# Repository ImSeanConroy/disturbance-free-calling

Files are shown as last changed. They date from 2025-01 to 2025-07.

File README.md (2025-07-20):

# Disturbance Free Calling

**Minimising disturbances to enable productive remote work** - In today's remote work environment, unintentional interruptions can disrupt productivity and communication. This project aims to solve that challenge by creating an IoT-powered availability indicator that minimizes disturbances during critical work activities such as calls and meetings.

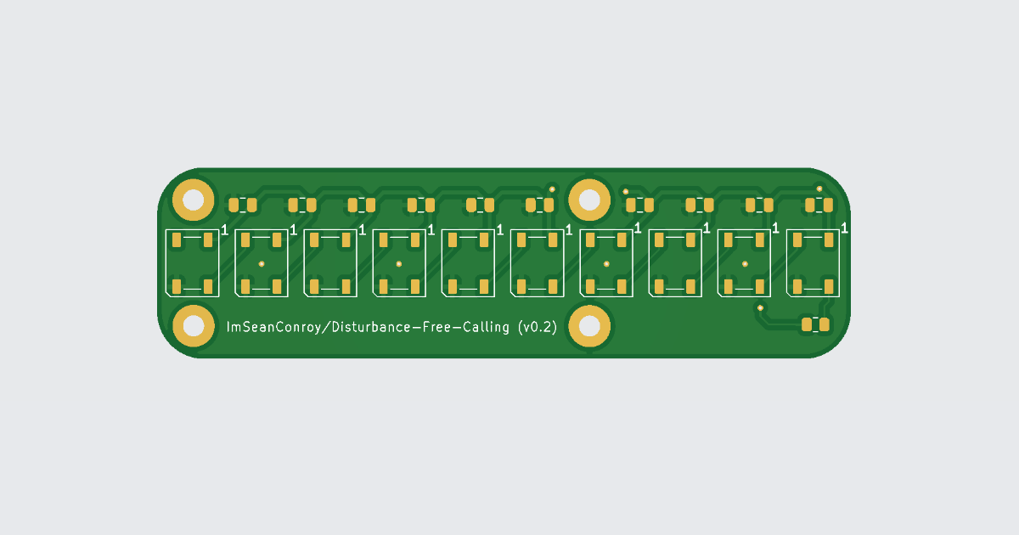
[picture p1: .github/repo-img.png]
Project Image


This is **version 2.0**, building on the foundations of the [original version](https://www.linkedin.com/feed/update/urn:li:activity:6930081862153342977) developed in 2020. The initial solution utilized an **ESP32 microcontroller based development board** to poll the **Webex API** and display availability using an **LED strip**.While effective, it had room for improvement in **performance, reliability, and design** — which are now addressed in this upgraded version.

## Table of Contents

- [Monorepo Structure](#monorepo-structure)
- [Features and Development Roadmap](#features-and-development-roadmap)
    - [Current Features](#current-features)
    - [Upcoming Features](#upcoming-features)
- [Architecture Diagram](#architecture-diagram)
- [Getting Started](#getting-started)
    - [1. Clone the Repository](#1-clone-the-repository)
    - [2. Hardware Setup](#2-hardware-setup)
    - [3. AWS Infrastructure Setup](#3-aws-infrastructure-setup)
    - [4. Firmware \& Device Setup](#4-firmware--device-setup)
    - [5. Configure Webex Webhook](#5-configure-webex-webhook)
- [Hardware Requirements](#hardware-requirements)
- [Contributing](#contributing)
- [License](#license)
- [Support](#support)
- [Acknowledgments](#acknowledgments)

## Monorepo Structure

This project uses a monorepo that includes:

- **Hardware** – KiCad PCB files for custom boards
- **Firmware** – ESP32 firmware to drive the LED indicator
- **AWS Infrastructure** – Terraform setup for API Gateway, Lambda, and IoT Core
- **Backend** – Node.js Lambda functions to handle Webex webhook data

## Features and Development Roadmap

This project is a work in progress, the following outlines the current features and planned improvements:

### Current Features

- **Terraform Provisioning** - Automates the setup and deployment of necessary cloud infrastructure.
- **Webhook Integration** - Allows seamless communication between the IoT device and external services.

### Upcoming Features

- **Custom PCB** - Designed specifically to support the IoT-driven indicator system.
- **Custom ESP32 Integration** - Incorporate the newly developed custom ESP32 board into the system architecture.
- **Web UI dashboard** - A web interface that allows users to override availability status manually.

## Architecture Diagram

Below is a high-level overview of how the architecture operates:

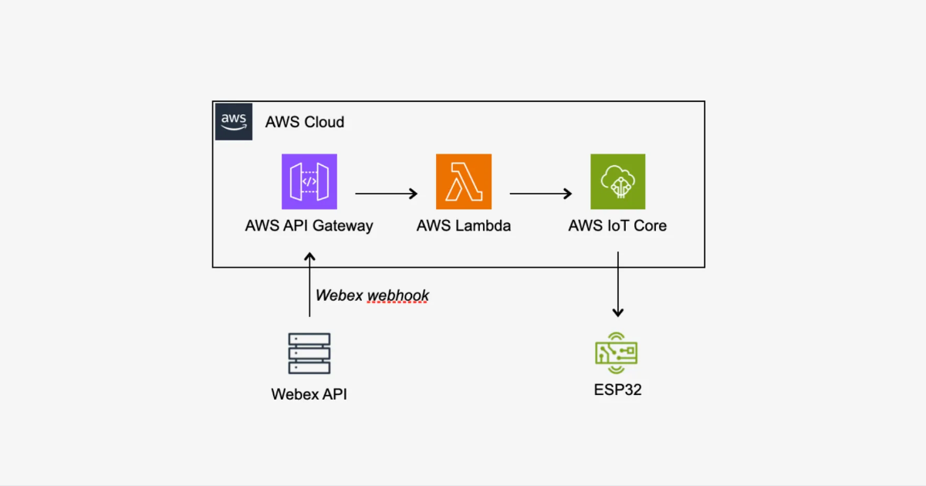
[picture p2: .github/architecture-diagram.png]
Architecure Diagram


**1. Webex Webhook → API Gateway** - A Webex webhook sends a request to an AWS API Gateway endpoint when a user’s availability status changes.

**2. Lambda Function → AWS IoT** - AWS API Gateway triggers an AWS Lambda function, which processes the Webex data and publishes the updated availability status to an AWS IoT Core MQTT topic.

**3. Device Subscribes → Updates LED** - The device subscribes to the AWS IoT topic and receives status updates, updatings the LED indicator accordingly.
 
> **Note**: A polling-based firmware version is available for setups that cannot use Webex webhooks. This version periodically queries the Webex API for status updates.

## Getting Started

Before getting started, ensure you have the following installed:

| Tool | Purpose | Link |
| --- | --- | --- |
| Node.js | Backend scripts & Lambda bundling | [Download](https://nodejs.org/) |
| npm | Node.js package manager | [Download](https://www.npmjs.com/) |
| Terraform | Infrastructure provisioning | [Install Guide](https://developer.hashicorp.com/terraform/install) |
| AWS CLI | AWS access & configuration | [AWS CLI](https://aws.amazon.com/cli/) |
| Arduino IDE | Firmware upload to ESP32 | [Arduino IDE](https://www.arduino.cc/en/software) |
| KiCad | Open/edit PCB files | [KiCad](https://www.kicad.org/) |

### 1. Clone the Repository

First, clone the repository to access the firmware, backend, and PCB files:

```bash
git clone https://github.com/ImSeanConroy/disturbance-free-calling.git
cd disturbance-free-calling
```

### 2. Hardware Setup

1. **Open the Project** - Open the `PCB/disturbance-free-calling.kicad_pro` file in KiCad to view the project.
2. **Review the Design** - Inspect the schematic and PCB layout to ensure it meets your needs.
3. **Customize or Export** - Make any modifications and export the Gerber files for fabrication.
4. **Order the PCB** - Submit the Gerber files to your preferred PCB manufacturer (e.g. [JLCPCB](https://jlcpcb.com/capabilities/pcb-capabilities)).
5. **Get the Components** - Purchase the components from the BOM and a compatible board.
6. **Assemble the Hardware** - Solder the components and assemble the board.

### 3. AWS Infrastructure Setup

1. **Zip AWS Lambda Function.**
```bash
cd Backend && npm run install && npm run zip && cd ..
```

2. **Configure Terraform Environment Variables.**
```bash
export AWS_ACCESS_KEY_ID=<your-access-key>
export AWS_SECRET_ACCESS_KEY=<your-secret-key>
export AWS_REGION=<your-region>
```

3. **Deploy AWS Infrastructure**
```bash
terraform init
terraform apply
```

4. **Extract AWS IoT Credentials** - Save these values and add them to your firmware:
```bash
terraform output root_ca_url
terraform output device_certificate
terraform output device_private_key
```

### 4. Firmware & Device Setup

1. **Open Firmware Sketch** - Load Firmware/AwsIotController/AwsIotController.ino in the Arduino IDE.
2. **Configure Device Credentials** - Add Wi-Fi SSID/password and paste the AWS IoT credentials into the appropriate constants.
3. **Upload to Device Firmware** - Compile and upload the sketch to the ESP32 using Arduino IDE. Test connectivity.

### 5. Configure Webex Webhook

> TODO: Add step-by-step instructions for setting up the Webex webhook and linking it to the API Gateway endpoint.

## Hardware Requirements

The following are the required components to build the 2x6 LED Matrix:

| Quantity | Component | Description | Source |
| - | - | - | - |
| 10 | WS2812B-V5 | Individually addressable RGB SMD LEDs | [TME](https://www.tme.eu/gb/details/ws2812b-v5/smd-colour-leds/worldsemi/) |
| 1 | Seeed XIAO ESP32C3 | Microcontroller board | [PiHut](https://thepihut.com/products/seeed-xiao-esp32c3?variant=53975115661697) |
| 1 | USB-A to USB-C Cable | For power and programming | [PiHut](https://thepihut.com/products/usb-a-to-usb-c-cable-1m?variant=42520360779971) |

## Contributing

Contributions are welcome. Please open an issue or submit a pull request for any enhancements or bug fixes.

## License

This project is Distributed under the MIT License - see the [LICENSE](LICENSE) file for information.

## Support

If you are having problems, please let me know by [raising a new issue](https://github.com/ImSeanConroy/disturbance-free-calling/issues/new/choose).

## Acknowledgments

This project was made possible thanks to the following resources:

- [AWS re:Post](https://repost.aws/questions/QUxlg-arOrTcaxFAdNEj7hqA/lambda-publish-a-mqtt-message-to-iot-core-inside-a-lambda-function-with-node-and-sdk-3) - Publish a MQTT Message to IOT Core inside a Lambda function with Node and SDK 3
- [AWS Samples](https://github.com/aws-samples/aws-iot-esp32-arduino-examples) - Several Arduino examples for AWS IoT projects using ESP32.

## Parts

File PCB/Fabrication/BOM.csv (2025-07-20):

Designator | Quantity | JLPCB Part # | Footprint
C2,C7,C3,C9,C8,C1,C5,C6,C4,C10 | 10 | C_0805_2012Metric | 100nF
D4,D1,D2,D3,D7,D8,D5,D9,D6,D10 | 10 | LED_WS2812B_PLCC4_5.0x5.0mm_P3.2mm | WS2812B
R1 | 1 | R_0805_2012Metric | 100uF
U1 | 1 | MOUDLE14P-SMD-2.54-21X17.8MM | MOUDLE-SEEEDUINO-XIAO-ESP32C3

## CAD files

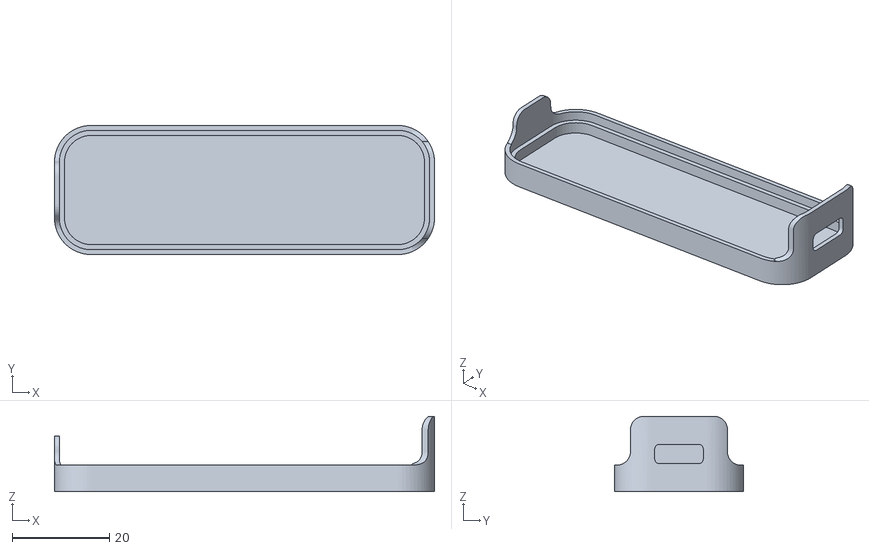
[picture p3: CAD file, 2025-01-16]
Case/back.stl
78.0 x 26.5 x 15.4

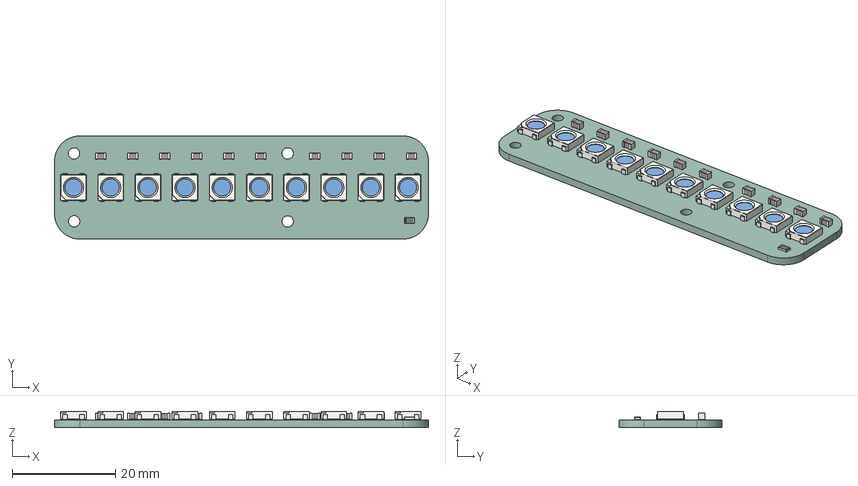
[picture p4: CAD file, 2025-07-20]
PCB/Fabrication/CAD.step
72.5 x 20.0 x 3.20 mm
C_0805_2012Metric x 10
LED_WS2812B_PLCC4_5.0x5.0mm_P3.2mm x 10
R_0805_2012Metric
disturbance-free-calling_PCB

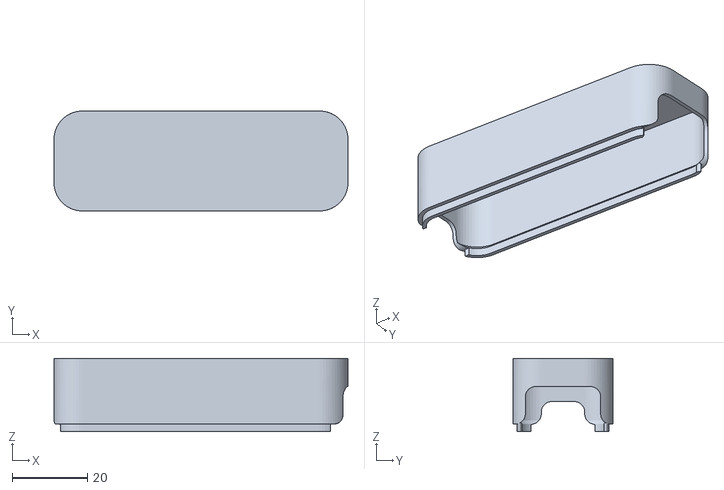
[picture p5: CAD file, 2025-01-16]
Case/front.stl
78.0 x 26.5 x 19.5

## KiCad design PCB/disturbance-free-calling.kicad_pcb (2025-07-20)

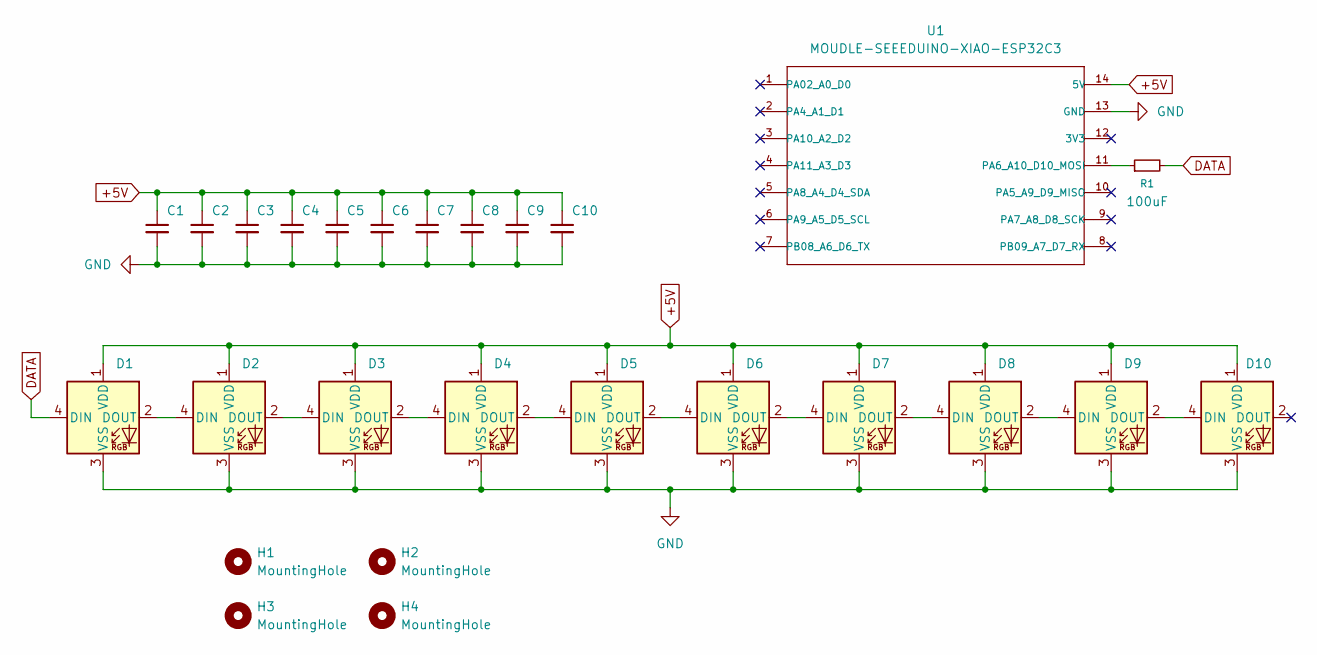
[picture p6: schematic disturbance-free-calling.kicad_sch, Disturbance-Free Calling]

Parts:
C1, C2, C3, C4, C5, C6, C7, C8, C9, C10: 100nF; C_0805_2012Metric
D1, D2, D3, D4, D5, D6, D7, D8, D9, D10: WS2812B; LED_WS2812B_PLCC4_5.0x5.0mm_P3.2mm
H1, H2, H3, H4: MountingHole; MountingHole_2.2mm_M2_Pad
R1: 100uF; R_0805_2012Metric
U1: MOUDLE-SEEEDUINO-XIAO-ESP32C3; MOUDLE14P-SMD-2.54-21X17.8MM

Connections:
+5V: C1.1, C2.1, C3.1, C4.1, C5.1, C6.1, C7.1, C8.1, C9.1, C10.1, D1.1 (VDD), D2.1 (VDD), D3.1 (VDD), D4.1 (VDD), D5.1 (VDD), D6.1 (VDD), D7.1 (VDD), D8.1 (VDD), D9.1 (VDD), D10.1 (VDD), U1.14 (5V)
DATA: D1.4 (DIN), R1.2
GND: C1.2, C2.2, C3.2, C4.2, C5.2, C6.2, C7.2, C8.2, C9.2, C10.2, D1.3 (VSS), D2.3 (VSS), D3.3 (VSS), D4.3 (VSS), D5.3 (VSS), D6.3 (VSS), D7.3 (VSS), D8.3 (VSS), D9.3 (VSS), D10.3 (VSS), U1.13 (GND)
unnamed: D1.2 (DOUT), D2.4 (DIN)
unnamed: D2.2 (DOUT), D3.4 (DIN)
unnamed: D3.2 (DOUT), D4.4 (DIN)
unnamed: D4.2 (DOUT), D5.4 (DIN)
unnamed: D5.2 (DOUT), D6.4 (DIN)
unnamed: D6.2 (DOUT), D7.4 (DIN)
unnamed: D7.2 (DOUT), D8.4 (DIN)
unnamed: D8.2 (DOUT), D9.4 (DIN)
unnamed: D9.2 (DOUT), D10.4 (DIN)
unnamed: R1.1, U1.11 (PA6_A10_D10_MOSI)

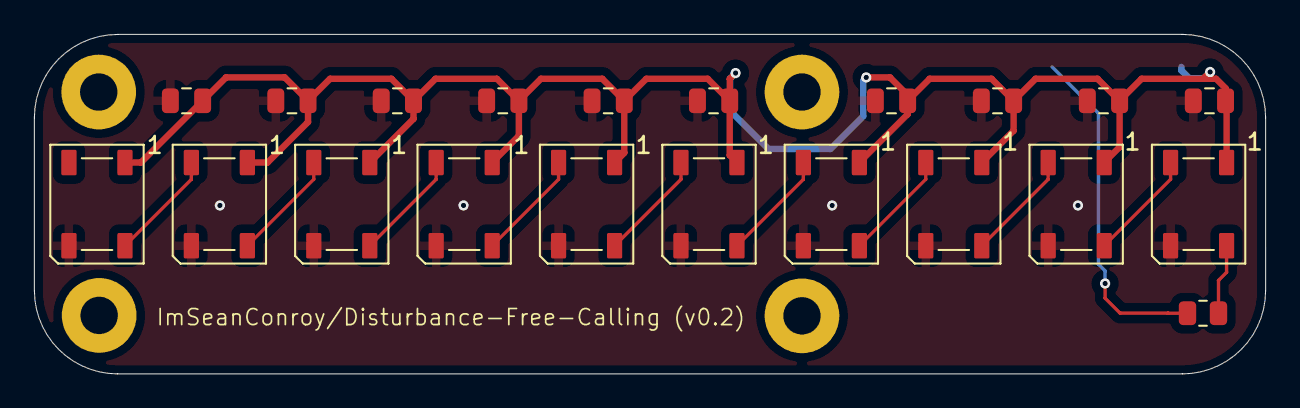
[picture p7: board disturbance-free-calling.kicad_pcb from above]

Board: 2 copper layers, 72.5 x 20.0 mm, 26 parts (1 on the bottom side), 13 nets.

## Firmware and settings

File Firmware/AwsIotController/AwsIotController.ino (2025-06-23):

/*
 * ============================================================
 * Project: Disturbance Free Calling
 * Developer: Sean Conroy
 * Board: Seeed Studio Xiao ESP32S3
 * License: MIT
 * Description:
 *   - Connects to AWS IoT Core using MQTT over a secure connection.
 *   - Subscribes to a predefined topic to receive real-time messages.
 *   - On receiving a message, the built-in LED blinks to signal incoming data.
 *   - Designed to enable quiet, non-intrusive notifications (e.g., for calls).
 *   - Uses WiFi credentials and certificates defined in "secrets.h".
 * ============================================================
 */

#include "secrets.h"
#include <WiFiClientSecure.h>
#include <MQTTClient.h>
#include <ArduinoJson.h>
#include "WiFi.h"

WiFiClientSecure net = WiFiClientSecure();
MQTTClient client = MQTTClient(256);

void connectAWS()
{
  // Connect to Wifi
  WiFi.mode(WIFI_STA);
  WiFi.begin(WIFI_SSID, WIFI_PASSWORD);

  Serial.print("Connecting to Wi-Fi");

  while (WiFi.status() != WL_CONNECTED){
    delay(500);
    Serial.print(".");
  }

  // Configure WiFiClientSecure to use the AWS IoT device credentials
  net.setCACert(AWS_CERT_CA);
  net.setCertificate(AWS_CERT_CRT);
  net.setPrivateKey(AWS_CERT_PRIVATE);

  // Connect to the MQTT broker on the AWS endpoint we defined earlier
  client.begin(AWS_IOT_ENDPOINT, 8883, net);

  // Create a message handler
  client.onMessage(messageHandler);

  Serial.println();
  Serial.print("Connecting to AWS IOT");

  while (!client.connect(THINGNAME)) {
    Serial.print(".");
    delay(100);
  }

  if(!client.connected()){
    Serial.println();
    Serial.print("AWS IoT Timeout.");
    return;
  }

  // Subscribe to a topic
  client.subscribe(AWS_IOT_SUBSCRIBE_TOPIC);
  Serial.println();
  Serial.print("AWS IoT Connected.");
}

void messageHandler(String &topic, String &payload) {
  Serial.println();
  Serial.println("Incoming: " + topic + " - " + payload);

  // Blink Built in LED
  digitalWrite(LED_BUILTIN, HIGH);
  delay(1000);  
  digitalWrite(LED_BUILTIN, LOW);
  delay(1000);
}

void setup() {
  Serial.begin(9600);
  pinMode(LED_BUILTIN, OUTPUT);
  connectAWS();
}

void loop() {
  client.loop();
  delay(1000);
}

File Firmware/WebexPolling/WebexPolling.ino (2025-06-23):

/*
 * ============================================================
 * Project: Disturbance Free Calling
 * Developer: Sean Conroy
 * Board: Seeed Studio Xiao ESP32S3
 * License: MIT
 * Description:
 *   - Connects to a Wi-Fi network using credentials from "secrets.h".
 *   - Polls the Webex API at a regular interval to retrieve user status.
 *   - Parses JSON response to extract current activity (e.g., in a call or meeting).
 *   - Lights up the built-in LED during busy statuses like "call", "meeting",
 *     "presenting", or "DoNotDisturb" to indicate unavailability.
 *   - Supports quiet visual notification to minimize interruptions.
 * ============================================================
 */

#include "secrets.h"
#include <ArduinoJson.h>
#include <WiFi.h>
#include <HTTPClient.h>

const char* WEBEX_ENDPOINT = "https://webexapis.com/v1/people/";
int polling_rate = 30000;

void connectToWiFi() {
  Serial.print("Connecting to Wi-Fi");
  WiFi.mode(WIFI_STA);
  WiFi.begin(WIFI_SSID, WIFI_PASSWORD);

  while (WiFi.status() != WL_CONNECTED) {
    delay(500);
    Serial.print(".");
  }
  Serial.println("\nConnected to Wi-Fi!");
}

String fetchWebexStatus() {
  if (WiFi.status() != WL_CONNECTED) {
    Serial.println("Wi-Fi not connected!");
    return "";
  }

  HTTPClient http;
  String fullUrl = String(WEBEX_ENDPOINT) + WEBEX_USER_ID;
  
  Serial.println("Requesting: " + fullUrl);
  http.begin(fullUrl);
  http.addHeader("Authorization", "Bearer " + String(WEBEX_API_KEY));
  http.addHeader("Content-Type", "application/json");

  int httpResponseCode = http.GET();
  String response = "";

  if (httpResponseCode > 0) {
    response = http.getString();
    Serial.println("Response: " + response);
  } else {
    Serial.print("HTTP Request failed, Code: ");
    Serial.println(httpResponseCode);
  }

  http.end();
  return response;
}

void setLEDState(const char* status) {
  if (strcmp(status, "call") == 0 || 
      strcmp(status, "meeting") == 0 || 
      strcmp(status, "presenting") == 0 || 
      strcmp(status, "DoNotDisturb") == 0) {
    digitalWrite(LED_BUILTIN, HIGH);
  } else {
    digitalWrite(LED_BUILTIN, LOW);
  }
}

void setup() {
  Serial.begin(9600);
  pinMode(LED_BUILTIN, OUTPUT);
  connectToWiFi();
}

void loop() {
  String response = fetchWebexStatus();
  if (!response.isEmpty()) {
    StaticJsonDocument<200> doc;
    DeserializationError error = deserializeJson(doc, response);

    if (!error) {
      const char* status = doc["status"];
      Serial.print("Status: ");
      Serial.println(status);
      setLEDState(status);
    } else {
      Serial.println("JSON Parsing Failed!");
    }
  }

  delay(polling_rate);
}

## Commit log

2024-11-24 Add aws iot cloud terraform configuration and arduino firmware to recieve messages
2025-01-16 Add work in progress case
    [back-wip.stl, front-wip.stl]
2025-02-09 Create initial pcb using seeed xaio esp32c3
    [BOM.csv, Component-Placement.csv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]
2025-02-09 Fix aws lambda permissions issue
    [aws_iot_controller.ino]
2025-02-20 Update aws configuration to use s3
    [BOM.csv]
2025-02-23 Create case for led strip version
    [back.stl, back_work_in_progress.stl, front.stl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]
2025-07-08 Convert to use ground plane
    [BOM.csv, Component-Placement.csv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]
2025-07-16 Rearrange layout
    [back.stl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]
2025-07-20 Add mounting holes
    [BOM.csv, CAD.step, Component-Placement.csv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]
